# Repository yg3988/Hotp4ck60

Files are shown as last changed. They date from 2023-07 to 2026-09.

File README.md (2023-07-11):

# Hotp4ck 60 - 60% Layout Custom Keyboard Schematic & PCB

This keyboard PCB is a ANSI 60% Layout with Bluetooth 5.4 support using the [nRF52840](https://www.nordicsemi.com/products/nrf52840) chip produced by [Nordic Semiconductor](https://www.nordicsemi.com/).

## Features

* Supported Bluetooth
* USB Type-C
* 1000mAh Li-Po Battery
    * Battery Connector : MOLEX [51021-0200](https://www.molex.com/en-us/products/part-detail/510210200)
    * Battery Connector Socket : MOLEX [PicoBlade 53261-0271](https://www.molex.com/en-us/products/part-detail/532610271)
    * Note :
        * If you change the battery capacity, You MUST program the battery chargin current by replacing `R4` at this [Schematic](/Hotp4ck_Battery.kicad_sch) for safety.
* No LED per key 
* No Underglow LEDs
* Split Space-bar(1.25u + 2.75u + 2.25u)

## Schematic

* [PDF Schematic](misc/Hotp4ck60_schemetic.pdf)

## PCB

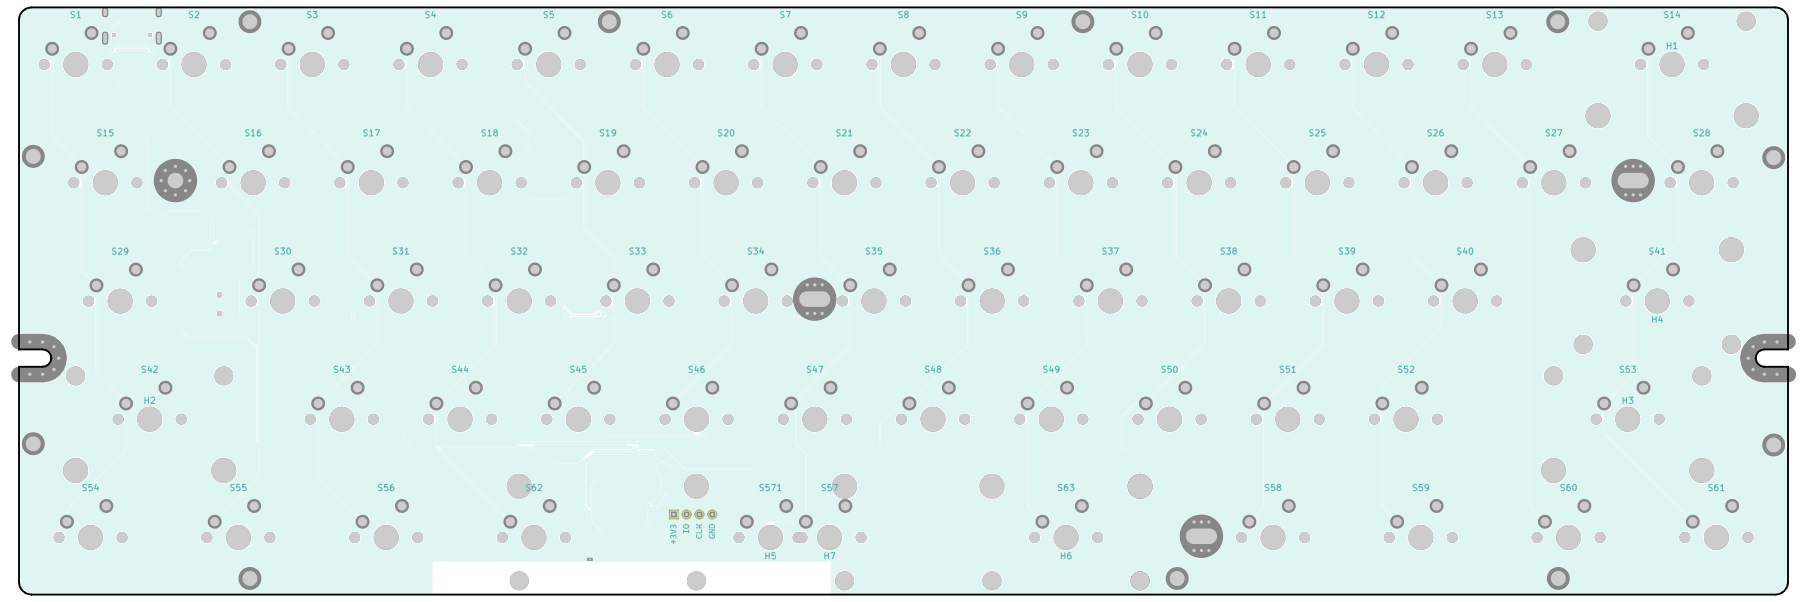
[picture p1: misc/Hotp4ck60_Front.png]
PCB_Front

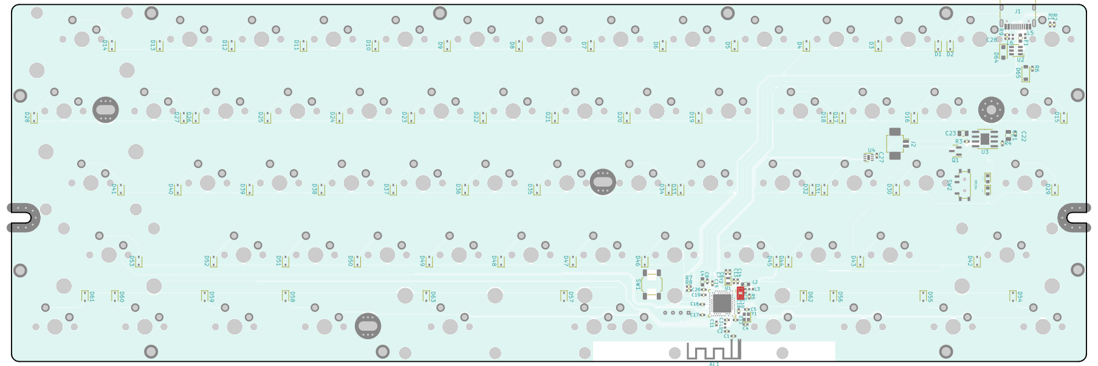
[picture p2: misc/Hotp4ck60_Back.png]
PCB_Back


Generated by [InteractiveHtmlBom](https://github.com/openscopeproject/InteractiveHtmlBom) plugin for KiCad.

## Keyboard Layout

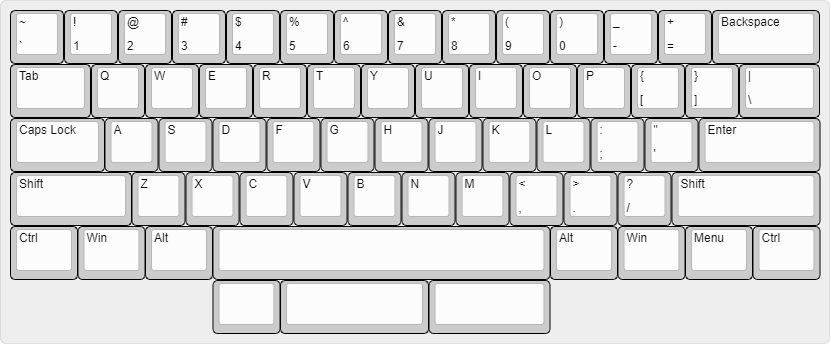
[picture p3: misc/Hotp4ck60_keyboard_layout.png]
Keyboard_Layout


## Bootloader & Firmware

* [Bootloader](https://github.com/yg3988/Adafruit_nRF52_Bootloader/actions)
    * Download Bootloader from the Recently `Actions/Artifacts`

* [Firmware](https://github.com/yg3988/zmk-config/actions/)
    * Download Firmware from the Recently `Actions/Artifacts`
 
## License
This keyboard PCB is licensed under the CERN Open Hardware Licence Version 2 - Permissive.

## References

* ### PCB Design : [zmk-designguide](https://github.com/ebastler/zmk-designguide) by [ebastler](https://github.com/ebastler)
* ### Firmware
    * ### ZMK : [zmk](https://github.com/zhiayang/zmk) by [zhiayang](https://github.com/zhiayang)
        > Source ZMK : zmkfirmware's [zmk](https://github.com/zmkfirmware/zmk)
    * ### [zmk-config](https://zmk.dev/docs/user-setup)
* ### Bootloader : [Adafruit_nRF52_Bootloader](https://github.com/adafruit/Adafruit_nRF52_Bootloader)

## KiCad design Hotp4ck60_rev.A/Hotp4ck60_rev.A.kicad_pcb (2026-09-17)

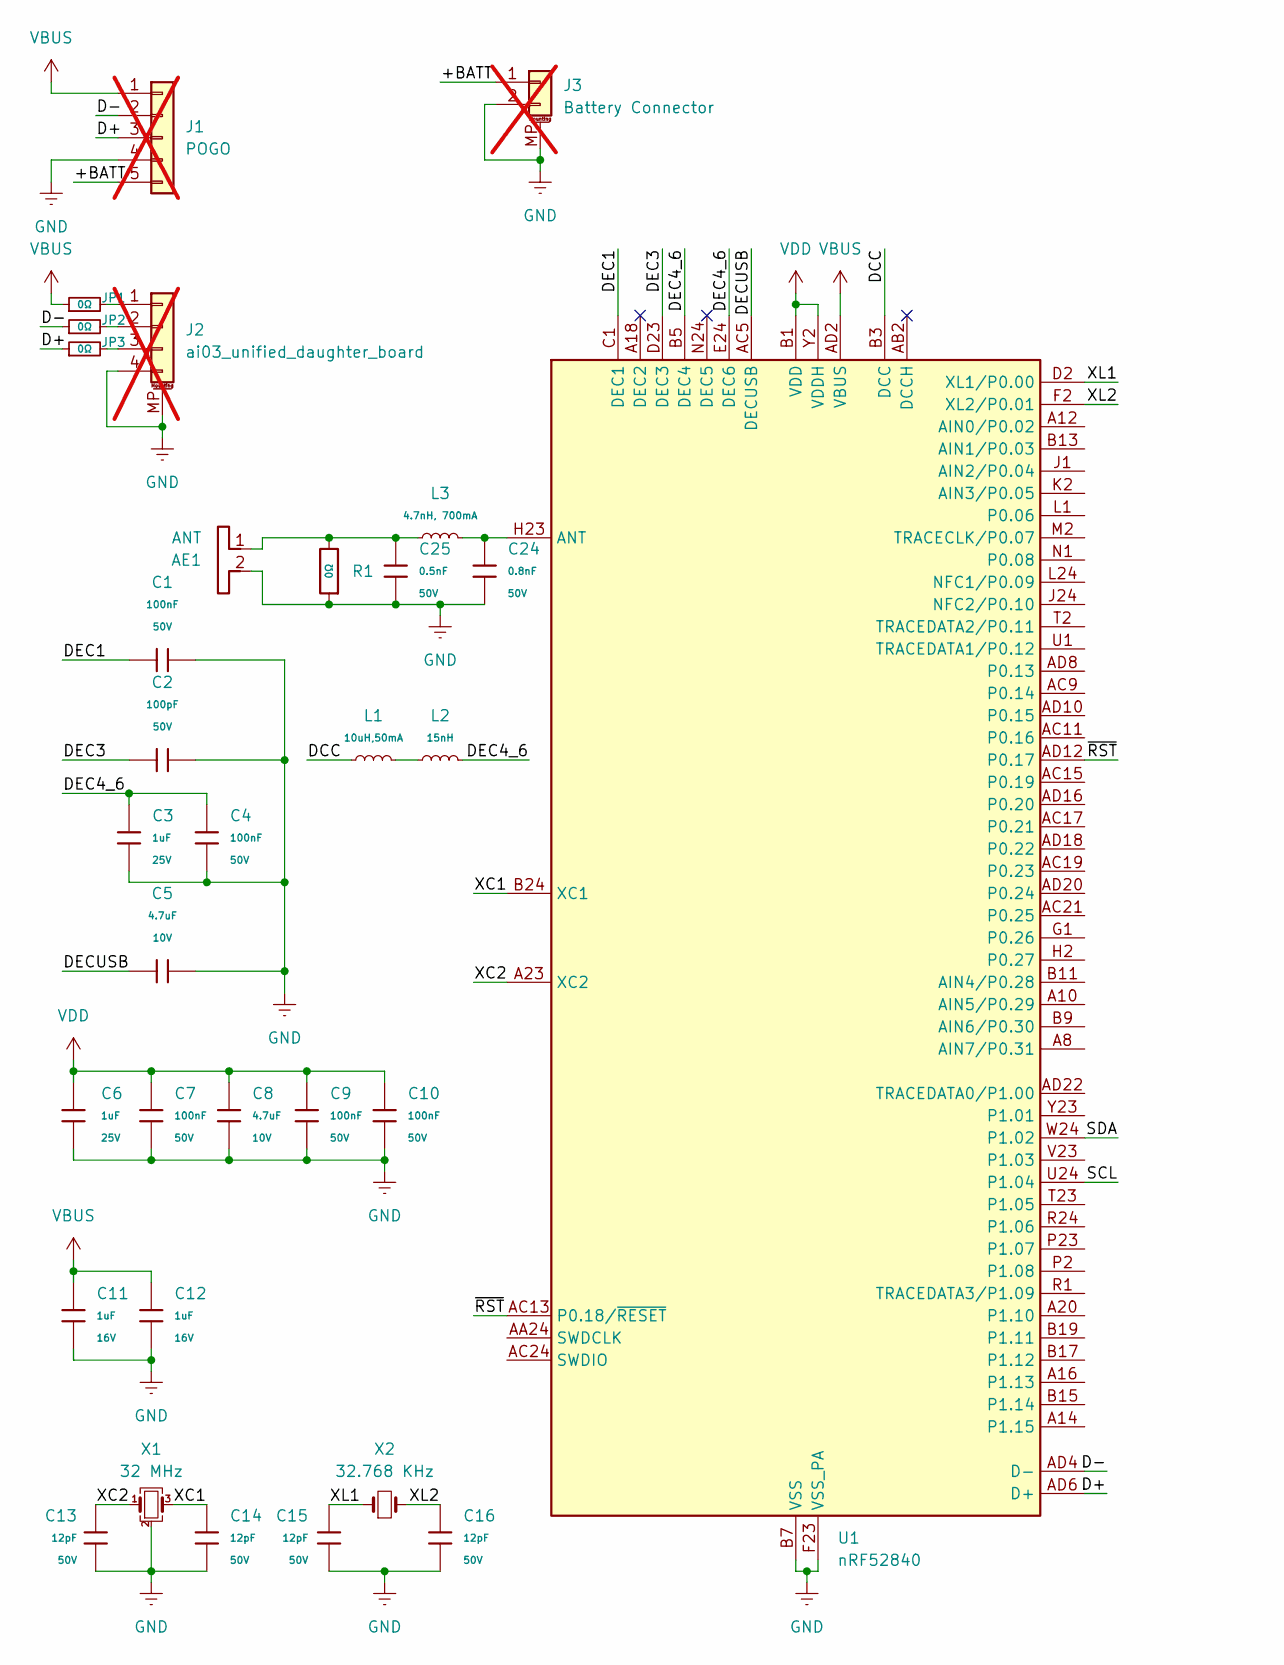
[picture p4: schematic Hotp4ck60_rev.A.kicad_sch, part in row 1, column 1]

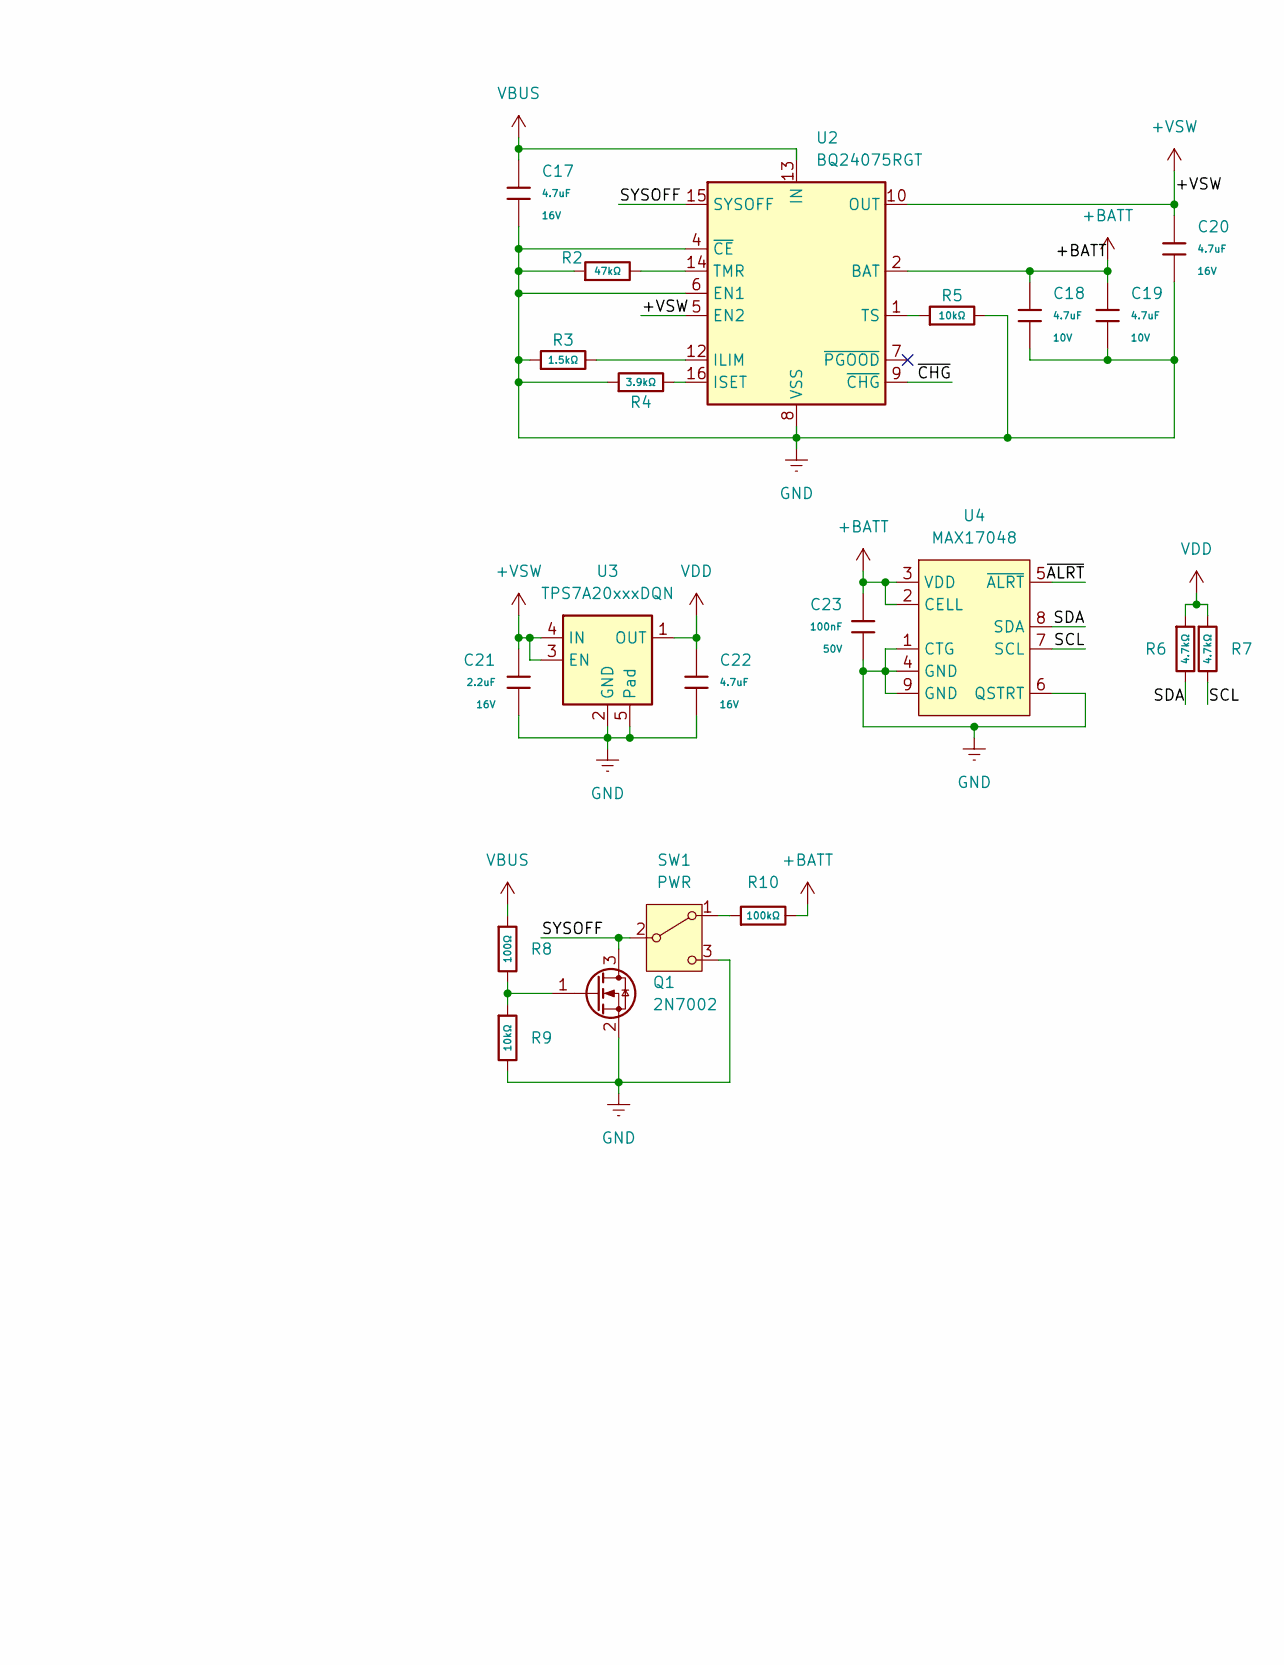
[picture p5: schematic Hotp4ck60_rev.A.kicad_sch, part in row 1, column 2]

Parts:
AE1: ANT; Texas_SWRA117D_2.4GHz_Right
C1, C4, C7, C9, C10, C23: 100nF; C_0402_1005Metric; Voltage Rated 50V; Tolerance ±10%; Part CL05B104KB54PNC; LCSC C307331
C2: 100pF; C_0402_1005Metric; Voltage Rated 50V; Tolerance ±5%; Part 0402CG101J500NT; LCSC C1546
C3, C6: 1uF; C_0402_1005Metric; Voltage Rated 25V; Tolerance ±10%; Part CL05A105KA5NQNC; LCSC C52923
C5, C8, C18, C19: 4.7uF; C_0402_1005Metric; Voltage Rated 10V; Tolerance ±20%; Part CL05A475MP5NRNC; LCSC C23733
C11, C12: 1uF; C_0402_1005Metric; Voltage Rated 16V; Tolerance ±10%; Part CL10A105KO8NNNC; LCSC C1592
C13, C14, C15, C16: 12pF; C_0402_1005Metric; Voltage Rated 50V; Tolerance ±5%; Part 0402CG120J500NT; LCSC C1547
C17, C20, C22: 4.7uF; C_0603_1608Metric; Voltage Rated 16V; Tolerance ±10%; Part CL10A475KO8NNNC; LCSC C19666
C21: 2.2uF; C_0603_1608Metric; Voltage Rated 16V; Tolerance ±10%; Part CL10A225KO8NNNC; LCSC C23630
C24: 0.8nF; C_0402_1005Metric; Voltage Rated 50V; Tolerance ±0.05pF; Part GJM1555C1HR80WB01D; LCSC C88902
C25: 0.5nF; C_0402_1005Metric; Voltage Rated 50V; Tolerance ±0.1pF; Part CC0402BRNPO9BNR50; LCSC C309456
J1: POGO; PinHeader_1x05_P2.54mm_Vertical; not fitted
J2: ai03_unified_daughter_board; JST_SH_SM04B-SRSS-TB_1x04-1MP_P1.00mm_Horizontal; not fitted
J3: Battery Connector; Molex_PicoBlade_53261-0271_1x02-1MP_P1.25mm_Horizontal; not fitted
JP1, JP2, JP3: 0Ω; R_0201_0603Metric
L1: 10uH,50mA; L_0603_1608Metric; Tolerance ±20%; Part APQM18FN100M00D; LCSC C50325679
L2: 15nH; L_0402_1005Metric; Tolerance ±5%; Part VHF100505HQ15NJT; LCSC C395049
L3: 4.7nH, 700mA; L_0402_1005Metric; Tolerance ±0.3nH; Part VHF100505HQ4N7ST; LCSC C395070
Q1: 2N7002; SOT-23
R1: 0Ω; R_0402_1005Metric; Overload Voltage (Max) 50V; Tolerance ±1%; Part 0402WGF0000TCE; LCSC C17168
R2: 47kΩ; R_0402_1005Metric; Overload Voltage (Max) 50V; Tolerance ±1%; Part 0402WGF4702TCE; LCSC C25792
R3: 1.5kΩ; R_0402_1005Metric; Overload Voltage (Max) 50V; Tolerance ±1%; Part 0402WGF1501TCE; LCSC C25867
R4: 3.9kΩ; R_0402_1005Metric; Overload Voltage (Max) 50V; Tolerance ±1%; Part 0402WGF3901TCE; LCSC C51721
R5, R9: 10kΩ; R_0402_1005Metric; Overload Voltage (Max) 50V; Tolerance ±1%; Part 0402WGF1002TCE; LCSC C25744
R6, R7: 4.7kΩ; R_0402_1005Metric; Overload Voltage (Max) 50V; Tolerance ±1%; Part 0402WGF4701TCE; LCSC C25900
R8: 100Ω; R_0402_1005Metric; Overload Voltage (Max) 50V; Tolerance ±1%; Part 0402WGF1000TCE; LCSC C25076
R10: 100kΩ; R_0402_1005Metric; Overload Voltage (Max) 50V; Tolerance ±1%; Part 0402WGF1003TCE; LCSC C25741
SW1: PWR; SW-SMD_SHOUHAN_MST-22D18G23J_C2875122
U1: nRF52840; Nordic_AQFN-73-1EP_7x7mm_P0.5mm
U2: BQ24075RGT; VQFN-16-1EP_3x3mm_P0.5mm_EP1.6x1.6mm
U3: TPS7A20xxxDQN; Texas_X2SON-4_1x1mm_P0.65mm
U4: MAX17048; DFN-8-1EP_2x2mm_P0.5mm_EP0.6x1.2mm
X1: 32 MHz; Crystal_SMD_2016-4Pin_2.0x1.6mm
X2: 32.768 KHz; Crystal_SMD_2012-2Pin_2.0x1.2mm

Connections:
+BATT: C18.2, C19.2, C23.1, J1.5, J3.1, R10.2, U2.2 (BAT), U2.3 (BAT), U4.2 (CELL), U4.3 (VDD)
+VSW: C20.1, C21.1, U2.5 (EN2), U2.10 (OUT), U2.11 (OUT), U3.3 (EN), U3.4 (IN)
/D+: J1.3, JP3.1, U1.AD6 (D+)
/D-: J1.2, JP2.1, U1.AD4 (D-)
/DCC: L1.1, U1.B3 (DCC)
/DEC1: C1.1, U1.C1 (DEC1)
/DEC3: C2.1, U1.D23 (DEC3)
/DEC4_6: C3.1, C4.1, L2.2, U1.B5 (DEC4), U1.E24 (DEC6)
/DECUSB: C5.2, U1.AC5 (DECUSB)
/SCL: R7.2, U1.U24 (P1.04), U4.7 (SCL)
/SDA: R6.2, U1.W24 (P1.02), U4.8 (SDA)
/SYSOFF: Q1.3 (D), SW1.2 (B), U2.15 (SYSOFF)
/XC1: C14.1, U1.B24 (XC1), X1.3
/XC2: C13.1, U1.A23 (XC2), X1.1
/XL1: C15.1, U1.D2 (XL1/P0.00), X2.1
/XL2: C16.1, U1.F2 (XL2/P0.01), X2.2
/~ALRT: U4.5 (~ALRT)
/~CHG: U2.9 (~CHG)
/~RST: U1.AC13 (P0.18/~RESET), U1.AD12 (P0.17)
GND: AE1.2, C1.2, C2.2, C3.2, C4.2, C5.1, C6.1, C7.1, C8.1, C9.1, C10.1, C11.1, C12.1, C13.2, C14.2, C15.2, C16.2, C17.2, C18.1, C19.1, C20.2, C21.2, C22.2, C23.2, C24.1, C25.1, J1.4, J2.4, J2.MP (MountPin), J3.2, J3.MP (MountPin), Q1.2 (S), R1.1, R2.1, R3.1, R4.1, R5.2, R9.2, SW1.3 (C), U1.B7 (VSS), U1.EP (VSS), U1.F23 (VSS_PA), U2.4 (~CE), U2.6 (EN1), U2.8 (VSS), U2.17 (VSS), U3.2 (GND), U3.5 (Pad), U4.1 (CTG), U4.4 (GND), U4.6 (QSTRT), U4.9 (GND), X1.2 (G), X1.4 (G)
unnamed: AE1.1, C25.2, L3.1, R1.2
unnamed: J2.1, JP1.2
unnamed: J2.2, JP2.2
unnamed: J2.3, JP3.2
unnamed: L1.2, L2.1
unnamed: Q1.1 (G), R8.2, R9.1
unnamed: R10.1, SW1.1 (A)
unnamed: C24.2, L3.2, U1.H23 (ANT)
unnamed: R3.2, U2.12 (ILIM)
unnamed: R4.2, U2.16 (ISET)
unnamed: R2.2, U2.14 (TMR)
unnamed: R5.1, U2.1 (TS)
VBUS: C11.2, C12.2, C17.1, J1.1, JP1.1, R8.1, U1.AD2 (VBUS), U2.13 (IN)
VDD: C6.2, C7.2, C8.2, C9.2, C10.2, C22.1, R6.1, R7.1, U1.A22 (VDD), U1.AD14 (VDD), U1.AD23 (VDD), U1.B1 (VDD), U1.W1 (VDD), U1.Y2 (VDDH), U3.1 (OUT)

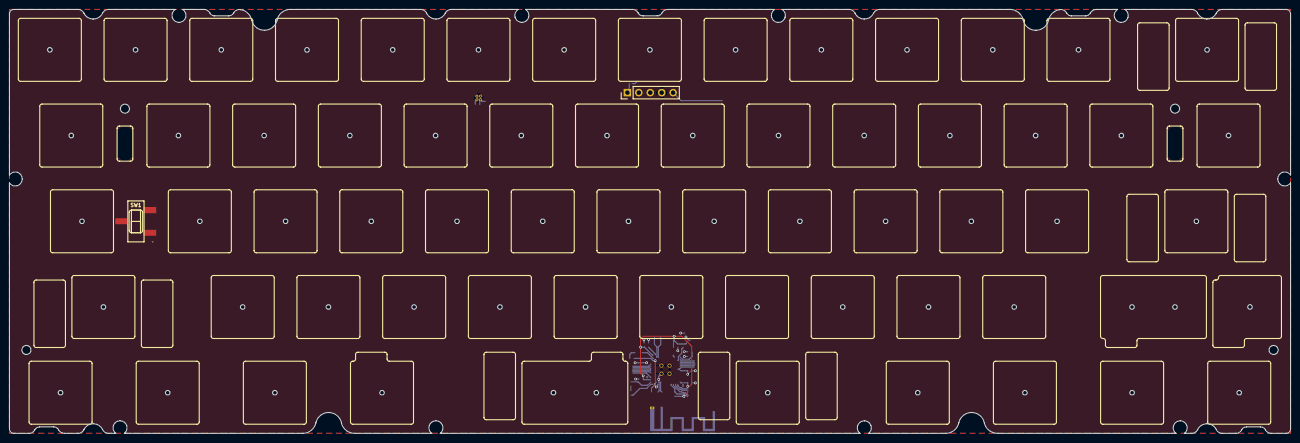
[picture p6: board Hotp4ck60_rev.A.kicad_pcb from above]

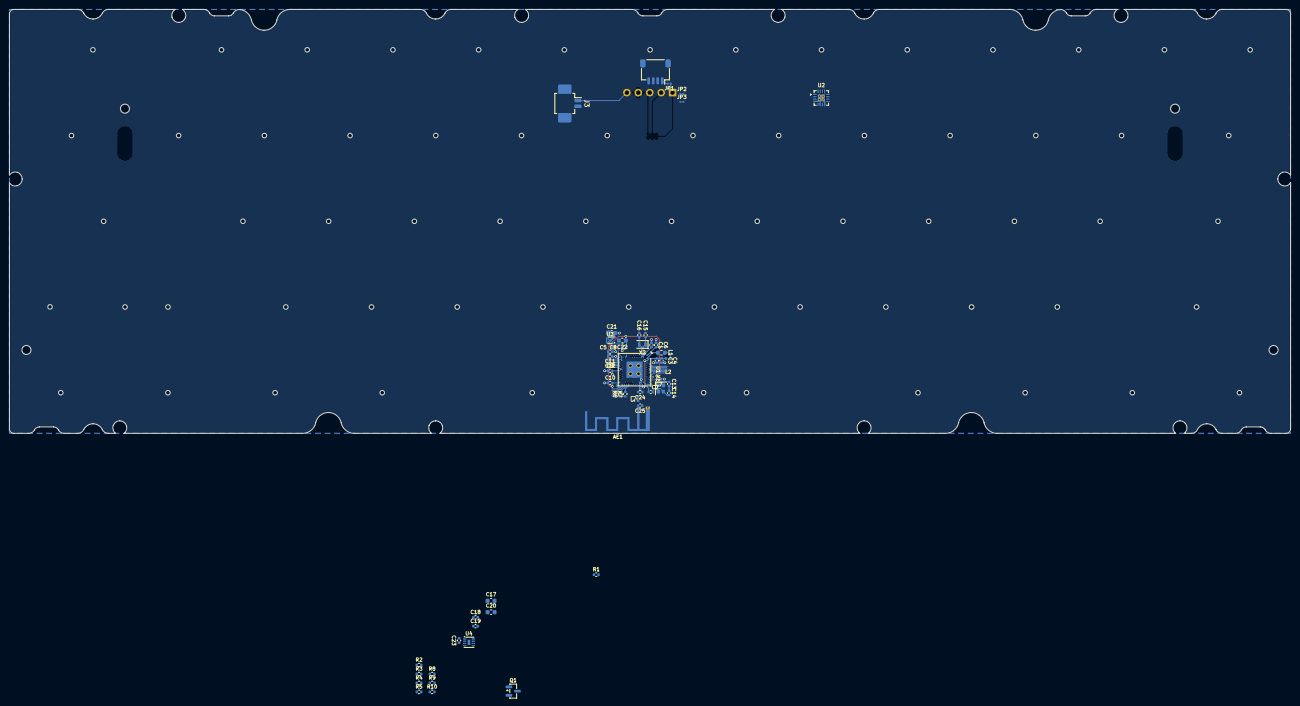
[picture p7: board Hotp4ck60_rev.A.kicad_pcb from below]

Board: 2 copper layers, 284.7 x 94.2 mm, 53 parts (51 on the bottom side), 32 nets.

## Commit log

2023-07-03 replace parts and change pin assignment.
    [Hotp4ck60.kicad_pcb, Hotp4ck60.kicad_sch, Hotpacky60_Matrix.kicad_sch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]
2023-07-03 Routing finished
    [Hotp4ck60-B_Cu.gbl, Hotp4ck60-B_Mask.gbs, Hotp4ck60-B_Paste.gbp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]
2023-07-04 Enter LCSC parts numbers
    [Hotp4ck60-B_Cu.gbl, Hotp4ck60-B_Mask.gbs, Hotp4ck60-B_Paste.gbp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]
2023-07-04 Fixed position & etc..
    [Hotp4ck60-B_Cu.gbl, Hotp4ck60-B_Mask.gbs, Hotp4ck60-B_Paste.gbp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]
2023-07-04 Generated Gerbers
    [Hotp4ck60-B_Cu.gbl, Hotp4ck60-B_Mask.gbs, Hotp4ck60-B_Paste.gbp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]
2023-07-05 Add Switch Mount pin symbol
    [Hotp4ck60-B_Cu.gbl, Hotp4ck60-B_Mask.gbs, Hotp4ck60-B_Paste.gbp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]
2023-07-06 Update parts position
    [Hotp4ck60-B_Cu.gbl, Hotp4ck60-B_Mask.gbs, Hotp4ck60-B_Paste.gbp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]
2023-07-06 Add keyboard layout and plate
    [Hotp4ck60.kicad_pcb, plate-2023-07-06T04_47_01.269Z.dxf]
2023-07-06 update schematic
    [Hotp4ck_Battery.kicad_sch]
2023-07-07 Change schematic
    [Hotp4ck60.kicad_pcb, Hotp4ck60.kicad_sch, Hotp4ck_Battery.kicad_sch]
2023-07-09 Update Svhematic
    [Hotp4ck_Battery.kicad_sch]
2023-07-11 Make Readme.md
    [Hotp4ck60.kicad_pcb, Hotp4ck60.kicad_sch, Hotp4ck_Battery.kicad_sch]
2023-07-22 Fixed Big Problem - Not connected cc1 or cc2 to GND
    [Hotp4ck60-B_Cu.gbl, Hotp4ck60-B_Mask.gbs, Hotp4ck60-B_Paste.gbp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]
2023-07-25 Fixed path
    [Hotp4ck60-B_Cu.gbl, Hotp4ck60-B_Mask.gbs, Hotp4ck60-B_Paste.gbp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]
2023-07-26 Modified PCB designed
    [Hotp4ck60.kicad_pcb, Hotp4ck60.kicad_sch]
2023-07-26 Modified positions
    [Hotp4ck60.kicad_pcb, Hotp4ck60.kicad_sch, Hotp4ck_Battery.kicad_sch]
2023-08-05 Revision Hotp4ck 60
    [Hotp4ck60.kicad_pcb, Hotp4ck60.kicad_sch, Hotp4ck_Battery.kicad_sch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]
2024-03-10 Create the Rev.B's gerbers and bom
    [Hotp4ck60-B_Cu.gbl, Hotp4ck60-B_Mask.gbs, Hotp4ck60-B_Paste.gbp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]
2024-05-13 Change to daugtherboard
    [Hotp4ck60.kicad_pcb, Hotp4ck60.kicad_sch, Hotp4ck_Battery.kicad_sch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]
2024-05-15 place parts and trace connect
    [Hotp4ck60.kicad_pcb, Hotp4ck60.kicad_sch, Hotpacky60_Matrix.kicad_sch]
2024-11-09 unified daughterboard, MCU 추가
    [Hotp4ck60.kicad_pcb, Hotp4ck60.kicad_sch, Hotp4ck_Battery.kicad_sch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]
2024-11-09 .gitignore 수정
2024-11-10 rev.c 핀, 트레이스 수정
    [Hotp4ck60.kicad_pcb, Hotp4ck60.kicad_sch]
2024-11-10 README 수정
    [Hotp4ck60.kicad_pcb, Hotpacky60_Matrix.kicad_sch]
2024-11-10 bom html파일 add
2024-11-23 LED 핀 수정
    [Hotp4ck60.kicad_pcb, Hotp4ck60.kicad_sch]
2025-06-03 rev.C neocore
    [Hotp4ck60.kicad_pcb, Hotp4ck60.kicad_sch, Hotpacky60_Matrix.kicad_sch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]
2025-06-03 전우너 관리 IC 타이머 저항 수정
    [Hotp4ck60.kicad_pcb, Hotp4ck60.kicad_sch]
2026-09-16 Clear My Keyboard
    [Hotp4ck60-B_Cu.gbl, Hotp4ck60-B_Mask.gbs, Hotp4ck60-B_Paste.gbp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]
2026-09-16 기판 아트웍 재시작
    [Hotp4ck60_rev.A.kicad_pcb, Hotp4ck60_rev.A.kicad_sch]
2026-09-17 키보드 기판 소자 재배치 중
    [Hotp4ck60_rev.A.kicad_pcb, Hotp4ck60_rev.A.kicad_sch]
